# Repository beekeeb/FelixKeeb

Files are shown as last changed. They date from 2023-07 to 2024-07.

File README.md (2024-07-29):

# FelixKeeb

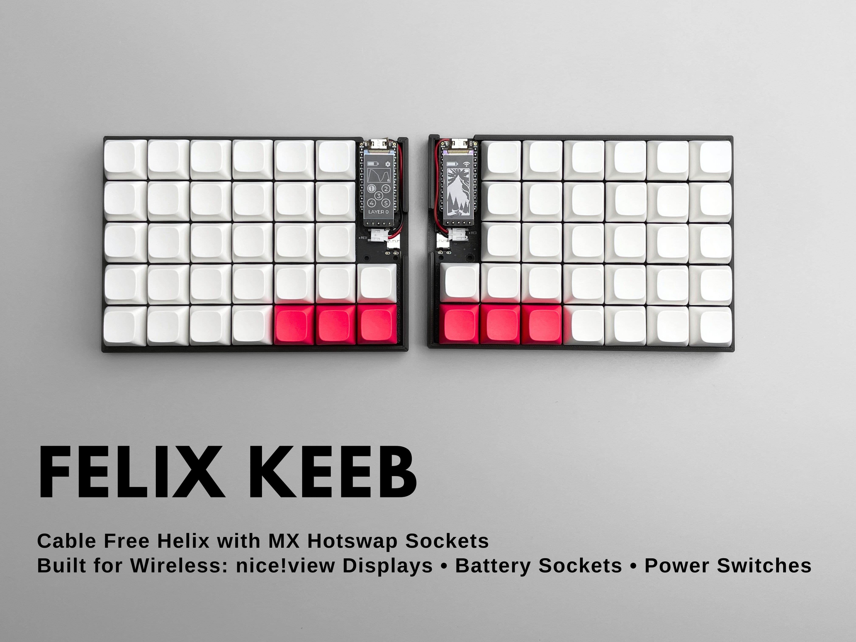
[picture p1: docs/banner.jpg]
FelixKeeb




The FelixKeeb is an open source 5×12+4 (5×6+2 on each side) split ortholinear keyboard with hotswap sockets support released by [beekeeb](https://beekeeb.shop). It is based on Cipulot’s [helixhschoc](https://github.com/cipulot/helixhschoc) and MakotoKurauchi’s [helix](https://github.com/MakotoKurauchi/helix).

## Quick Links

* [Precompiled firmware](https://docs.beekeeb.com/felixkeeb#precompiled-firmware)
* [beekeeb showcase](https://showcase.beekeeb.com/felixkeeb/)

## Firmware

* [QMK](https://github.com/qmk/qmk_firmware) - compatible with helix/rev2
* [Vial](https://github.com/vial-kb/vial-qmk) (based on QMK) - supported
* [ZMK](https://github.com/zmkfirmware/zmk) - supported

Precompiled firmware can be found at https://docs.beekeeb.com/felixkeeb.

## Features

* Hotswap Sockets: Changing key switches whenever you want

### Wireless

* nice!view support
* Onboard JST battery sockets: no battery soldering required & easily swapping batteries
* Power (on/off) switches: saving power by turning off the keyboard when it is not in used

### Wired

* OLED display support
* USB-C connectors: No pin shorting problems caused by TRRS jacks
* Compatible with Helix/rev2 VIAL Firmware

## Case
* A basic case using with MX key switches is [available in Printables](https://www.printables.com/model/957449).

## License



Photos, logos, external symbols and footprints are not covered by the LICENSE in this repo.

External symbols and footprints:

* [foostan/kbd](http://github.com/foostan/kbd)
* [nice_view.pretty](https://github.com/petejohanson/crkbd/tree/board/corne-ultralight/corne-ultralight/pcb/nice_view.pretty) from petejohanson's [Corne Ultralight](https://github.com/petejohanson/crkbd/tree/board/corne-ultralight)

## Credits

This open source hardware project is created by [beekeeb](https://beekeeb.shop) and other contributors. It is based on Cipulot’s [helixhschoc](https://github.com/cipulot/helixhschoc) and MakotoKurauchi’s [helix](https://github.com/MakotoKurauchi/helix).

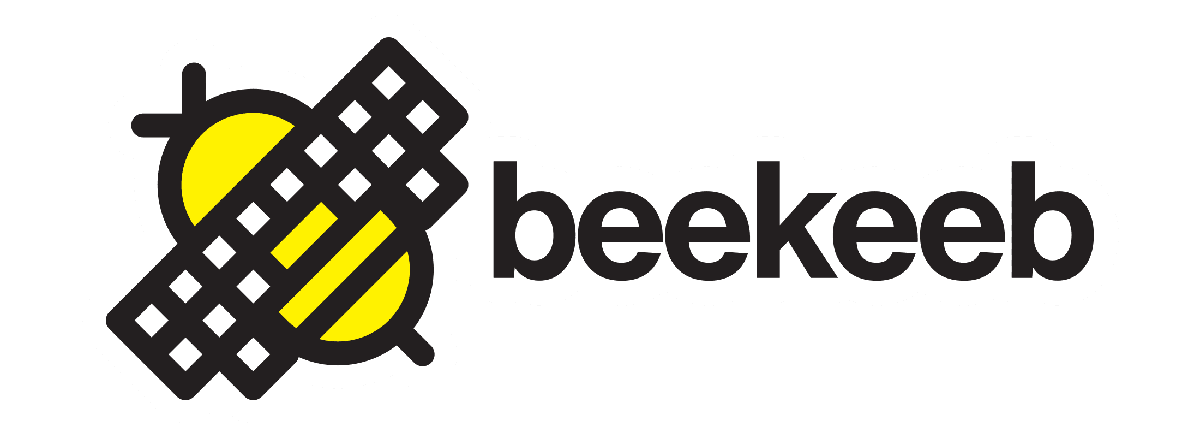
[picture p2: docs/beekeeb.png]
[](https://beekeeb.shop)

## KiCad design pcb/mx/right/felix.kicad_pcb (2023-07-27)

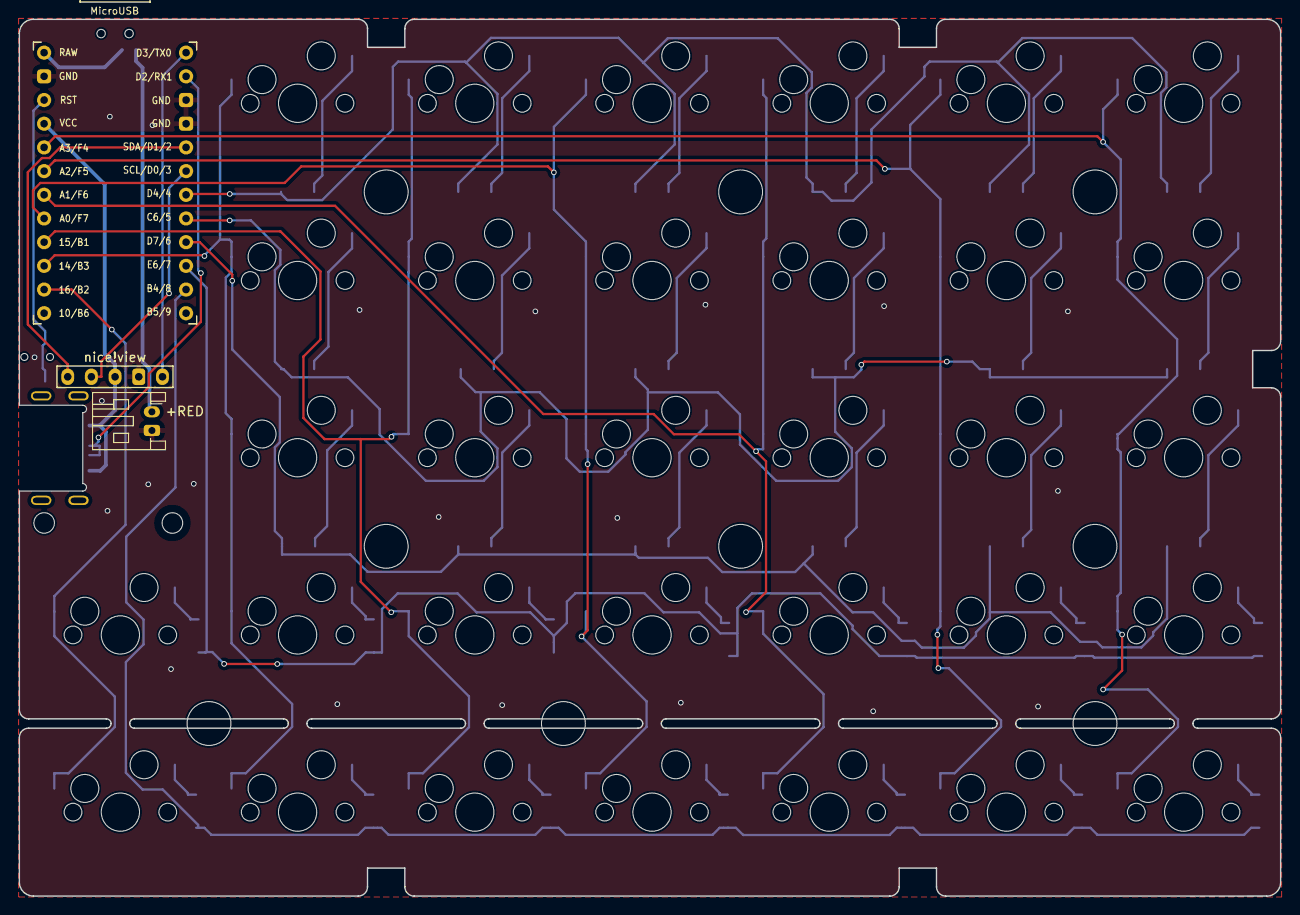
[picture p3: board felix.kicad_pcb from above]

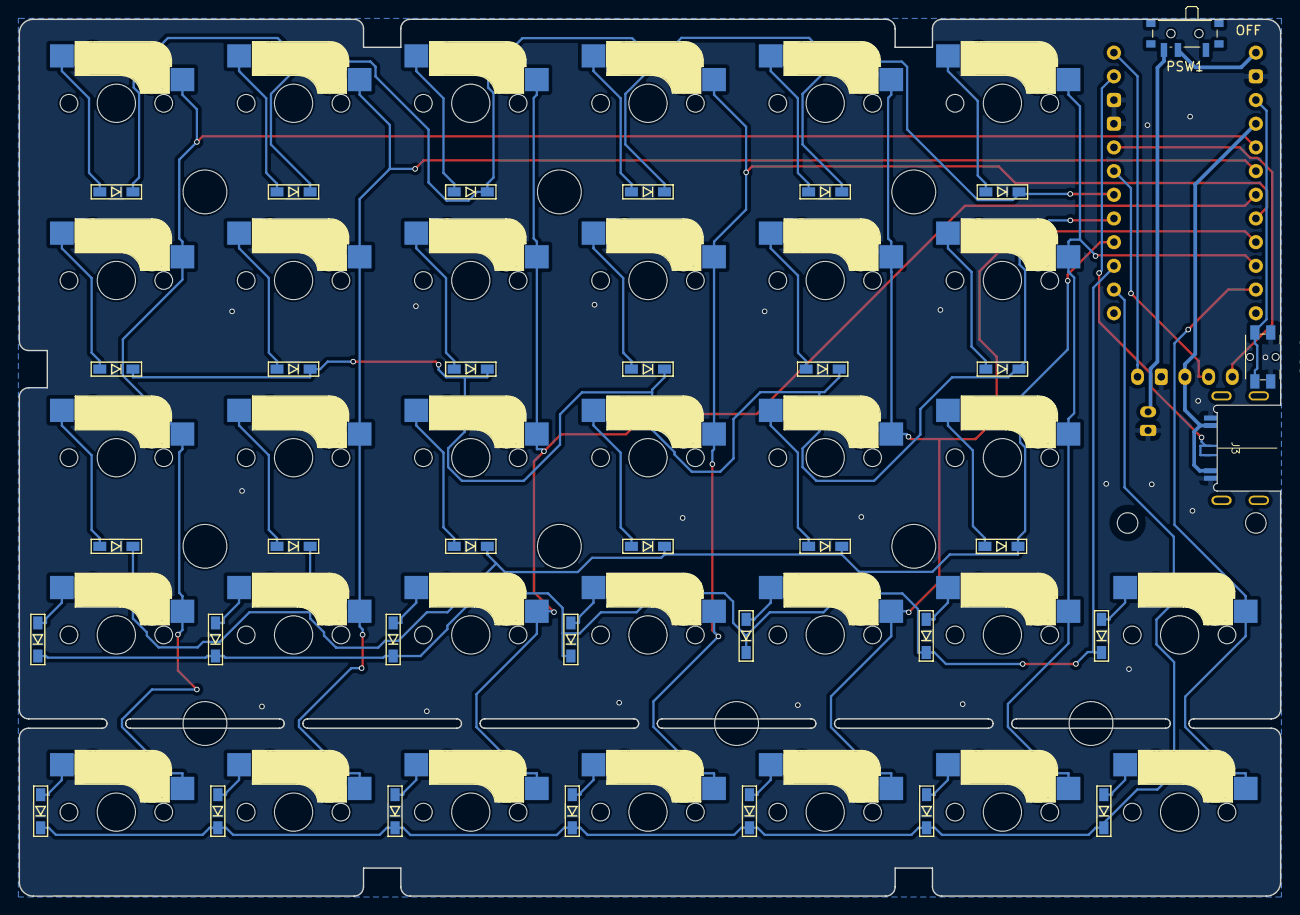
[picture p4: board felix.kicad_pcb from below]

Board: 2 copper layers, 135.2 x 94.0 mm, 81 parts (46 on the bottom side), 53 nets.

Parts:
BATJ1: Conn_01x02_Female; JST_PH_S2B-PH-K_1x02_P2.00mm_Horizontal
D1, D2, D3, D4, D5, D6, D7, D8, D9, D10, D11, D12, D13, D14, D15, D16, D17, D18, D19, D20, D21, D22, D23, D24, D25, D26, D27, D28, D29, D30, D31, D32: D; D3_SMD_v2
H1, H2, H3, H4, H5, H6, H7, H8, H9: MountingHole; HOLE_M2_TH
H10, H13: MountingHole; HOLE_M2
J2: OLED; nice_view_1side
J3: USB_C_Receptacle; TYPE-C-31-M-14-custom-summer
PSW1: SW_SPST; SW_SPDT_PCM12
SW1, SW2, SW3, SW4, SW5, SW6, SW7, SW8, SW9, SW10, SW11, SW12, SW13, SW14, SW15, SW16, SW17, SW18, SW19, SW20, SW21, SW22, SW23, SW24, SW25, SW26, SW27, SW28, SW29, SW30, SW31, SW32: SW_PUSH; CherryMX_Hotswap
SW33: Reset; Panasonic_EVQPUL_EVQPUC
U1: ProMicro; ProMicro_v3

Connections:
+BATT: PSW1.2 (B), U1.24 (RAW)
/~RESET: SW33.2, U1.22 (RESET)
CS: J2.5, U1.1 (TXO(PD3))
GND: BATJ1.2, J2.4, J3.A1 (GND), SW33.1, U1.3 (GND), U1.4 (GND), U1.23 (GND)
unnamed: BATJ1.1, PSW1.3 (C)
unnamed: D1.2 (A), SW1.2
unnamed: D2.2 (A), SW2.2
unnamed: D3.2 (A), SW3.2
unnamed: D4.2 (A), SW4.2
unnamed: D5.2 (A), SW5.2
unnamed: D6.2 (A), SW6.2
unnamed: D7.2 (A), SW7.2
unnamed: D8.2 (A), SW8.2
unnamed: D9.2 (A), SW9.2
unnamed: D10.2 (A), SW10.2
unnamed: D11.2 (A), SW11.2
unnamed: D12.2 (A), SW12.2
unnamed: D13.2 (A), SW13.2
unnamed: D14.2 (A), SW14.2
unnamed: D15.2 (A), SW15.2
unnamed: D16.2 (A), SW16.2
unnamed: D17.2 (A), SW17.2
unnamed: D18.2 (A), SW18.2
unnamed: D19.2 (A), SW19.2
unnamed: D20.2 (A), SW20.2
unnamed: D21.2 (A), SW21.2
unnamed: D22.2 (A), SW22.2
unnamed: D23.2 (A), SW23.2
unnamed: D24.2 (A), SW24.2
unnamed: D25.2 (A), SW25.2
unnamed: D26.2 (A), SW26.2
unnamed: D27.2 (A), SW27.2
unnamed: D28.2 (A), SW28.2
unnamed: D29.2 (A), SW29.2
unnamed: D30.2 (A), SW30.2
unnamed: D31.2 (A), SW31.2
unnamed: D32.2 (A), SW32.2
SCL: J2.2, U1.6 (D3(PD0))
SDA: J2.1, U1.5 (D2(PD1))
VCC: J2.3, J3.A4 (VBUS), U1.21 (VCC)
col0: SW1.1, SW7.1, SW13.1, SW19.1, SW26.1, U1.20 (A3(PF4))
col1: SW2.1, SW8.1, SW14.1, SW20.1, SW27.1, U1.19 (A2(PF5))
col2: SW3.1, SW9.1, SW15.1, SW21.1, SW28.1, U1.18 (A1(PF6))
col3: SW4.1, SW10.1, SW16.1, SW22.1, SW29.1, U1.17 (A0(PF7))
col4: SW5.1, SW11.1, SW17.1, SW23.1, SW30.1, U1.16 (SCK(PB1))
col5: SW6.1, SW12.1, SW18.1, SW24.1, SW31.1, U1.15 (MISO(PB3))
col6: SW25.1, SW32.1, U1.14 (MOSI(PB2))
data: J3.A7 (D-), J3.B7 (D-), U1.2 (RXI(PD2))
row0: D1.1 (K), D2.1 (K), D3.1 (K), D4.1 (K), D5.1 (K), D6.1 (K), U1.7 (D4(PD4))
row1: D7.1 (K), D8.1 (K), D9.1 (K), D10.1 (K), D11.1 (K), D12.1 (K), U1.8 (D5(PC6))
row2: D13.1 (K), D14.1 (K), D15.1 (K), D16.1 (K), D17.1 (K), D18.1 (K), U1.9 (D6(PD7))
row3: D19.1 (K), D20.1 (K), D21.1 (K), D22.1 (K), D23.1 (K), D24.1 (K), D25.1 (K), U1.10 (D7(PE6))
row4: D26.1 (K), D27.1 (K), D28.1 (K), D29.1 (K), D30.1 (K), D31.1 (K), D32.1 (K), U1.11 (D8(PB4))

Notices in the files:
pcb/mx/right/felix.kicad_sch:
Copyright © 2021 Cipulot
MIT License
